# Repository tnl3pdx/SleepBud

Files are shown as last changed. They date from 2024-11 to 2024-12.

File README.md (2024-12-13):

## ECE 411 Team 3 - SleepBud
## Members
- Ameer Melli
- Cristian Gomez
- Paul Nguyen
- Truong Le

## Product Overview
Sleep Bud transcends the functionality of a simple alarm clock, serving as a comprehensive sleep companion designed to enhance your sleep quality. It features mood-inducing lights and gentle non-intrusive waking sounds. Essentially, this innovative device is a hybrid between a traditional alarm clock and a multi-color lamp.
Why?? Because according to the CDC 70 million Americans have chronic sleep problems and the current market solutions are too expensive. 

## User Manual for SleepBud

Mode 0: (normal mode indicated by teal colored colon)
- This will be where the clock will display the appropriate time.
- (mode button) Button 0 pressed in mode 0 will change the mode.
- (plus button) Button 1 pressed in mode 0 will increase the brightness of the lamp.
- (minus button) Button 2 pressed in mode 0 will decrease the brightness of the lamp.
- (select button) Button 3 pressed in mode 0 will cycle through lamp colors.

- In mode 0, when the alarm is set the bottom colon will be purple indicating the alarm is set.
- In mode 0, when the alarm is set, button 3 (the select button) acts as a snooze button.

- In mode 0, when in AM time (00:00 - 12:00) the digits will be a warm color (orange).
- In mode 0, when in PM time (12:00 - 24:00) the digits will be a cool color (white).

- In mode 0, when waving your hand over the alarm, the PIR sensor will automatically turn off the lamp if it is on and if it is off, it will turn it on.

Mode 1: (configuration time mode indicated by red colored colon)
- This will be where the user can manually set the clock time.
- (mode button) Button 0 pressed in mode 1 will cycle to the next mode and set the new time.
- (plus button) Button 1 pressed in mode 1 will increase the value of the selected section for the manual time.
- (minus button) Button 2 pressed in mode 1 will decrease the value of the selected section for the manual time.
- (select button) Button 3 pressed in mode 1 will cycle through the digits.

Mode 2: (enable alarm mode indicated by green colored colon)
- This will be for toggling the alarm on and off.
- (mode button) Button 0 pressed in mode 2 will cycle to the next mode and set the alarm.
- (plus button) Button 1 pressed in mode 2 will toggle on (1).
- (minus button) Button 2 pressed in mode 2 will toggle off (0).

Mode 3: (configuration alarm mode indicated by purple colored colon)
- This is for setting the alarm time.
- (mode button) Button 0 pressed in mode 3 will cycle to the next mode and set the new alarm time.
- (plus button) Button 1 pressed in mode 3 will increase the value of the selected section for the alarm time.
- (minus button) Button 2 pressed in mode 3 will decrease the value of the selected section for the alarm time.
- (select button) Button 3 pressed in mode 3 will cycle through the digits colors.

Mode 4: (select UTC mode indicated by yellow colored colon)
- This sets the UTC offset.
- (mode button) Button 0 pressed in mode 4 will cycle to the next mode and set the new UTC offset.
- (plus button) Button 1 pressed in mode 4 will increase the value of the selected section for the UTC offset.
- (minus button) Button 2 pressed in mode 4 will decrease the value of the selected section for the UTC offset.

- In mode 4, when indicating what UTC offset you want when adding a positive offset the digits will be green.
- In mode 4, when indicating what UTC offset you want when adding a negative offset the digits will be red.

Mode 5: (enable NTP update mode indicated by pink colored colon)
- This enables time fetch from wifi and applies UTC offset.
- (mode button) Button 0 pressed in mode 5 will cycle to the next mode and set enable NTP.
- (plus button) Button 1 pressed in mode 5 will toggle on (1).
- (minus button) Button 2 pressed in mode 5 will toggle off (0).

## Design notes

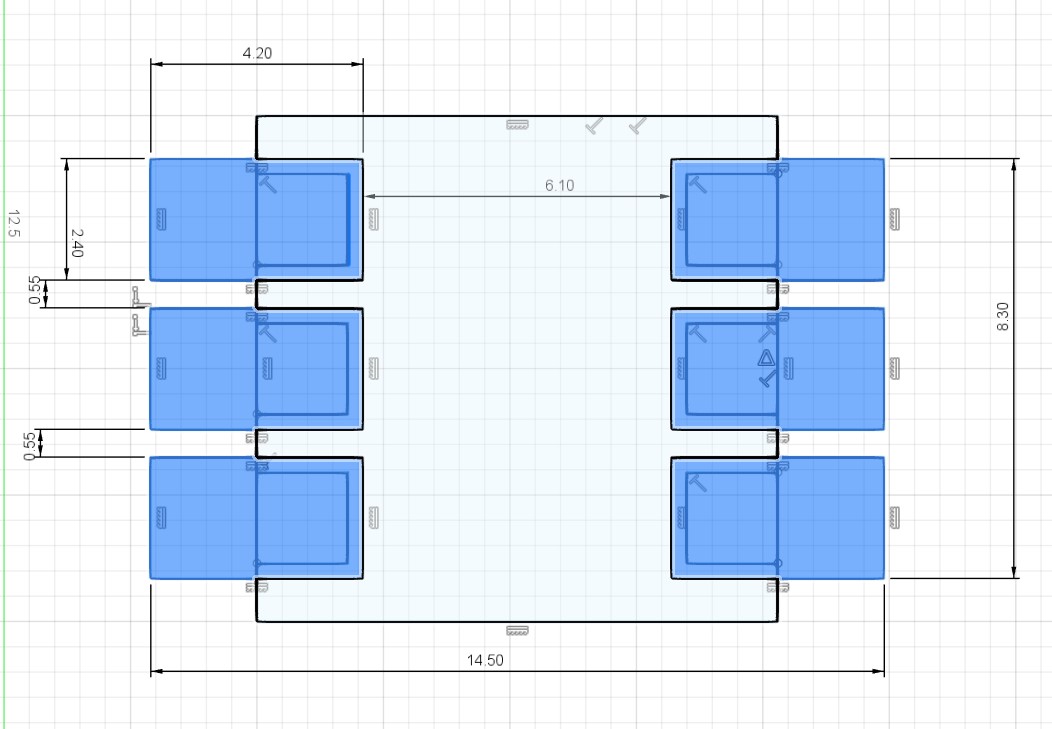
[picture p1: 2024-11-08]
Images/Sketches/WS2128B-CustomPadLayout.jpg

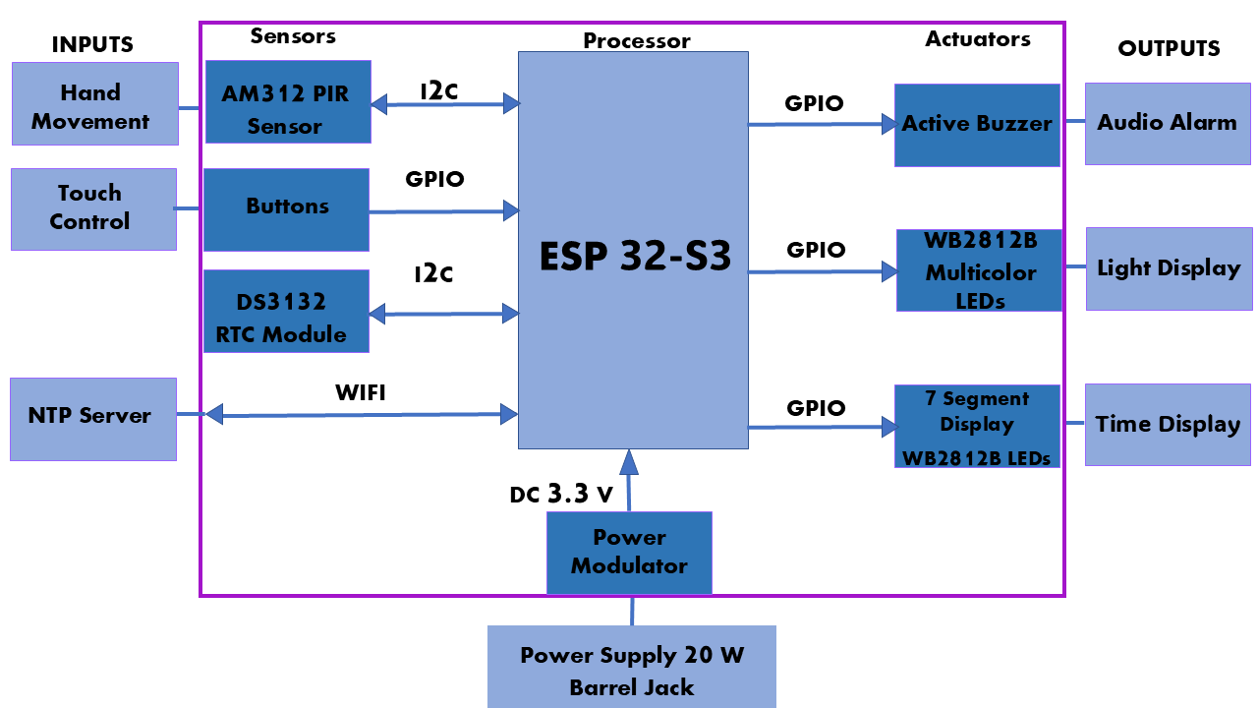
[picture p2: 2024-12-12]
Images/Sketches/L1 v3.png

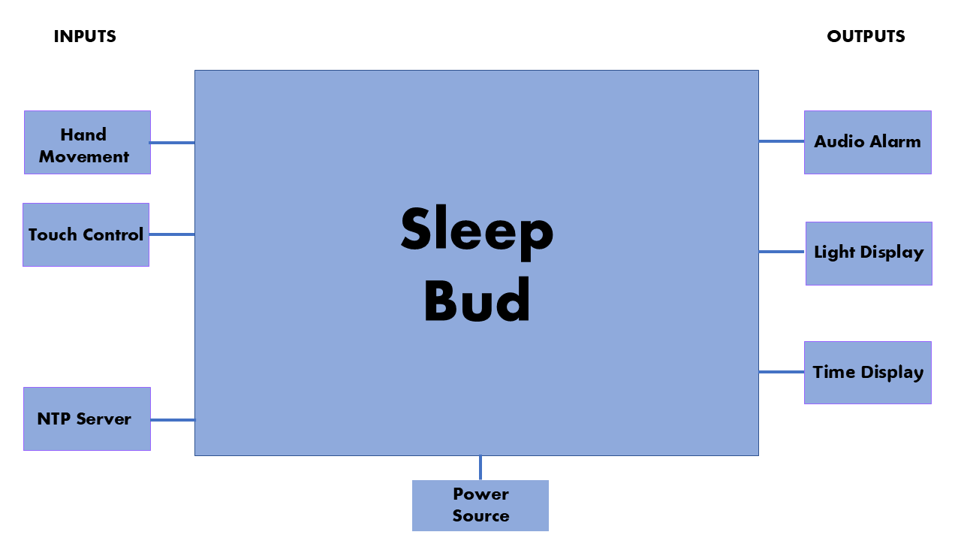
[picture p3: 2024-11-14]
Images/Sketches/L0 v2.png

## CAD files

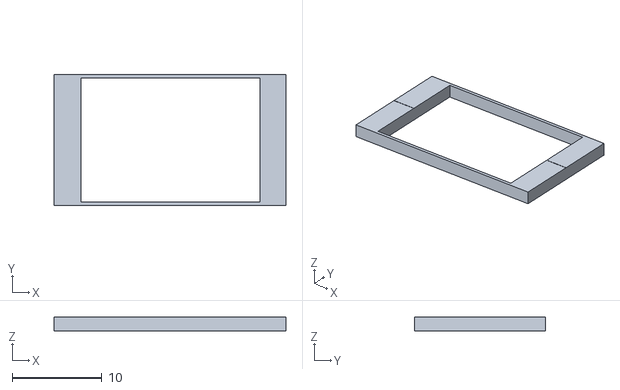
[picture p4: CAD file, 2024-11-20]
3D_Prints/Extra Parts/KillSwitch_V2_ECE411.stl
25.9 x 14.6 x 1.60

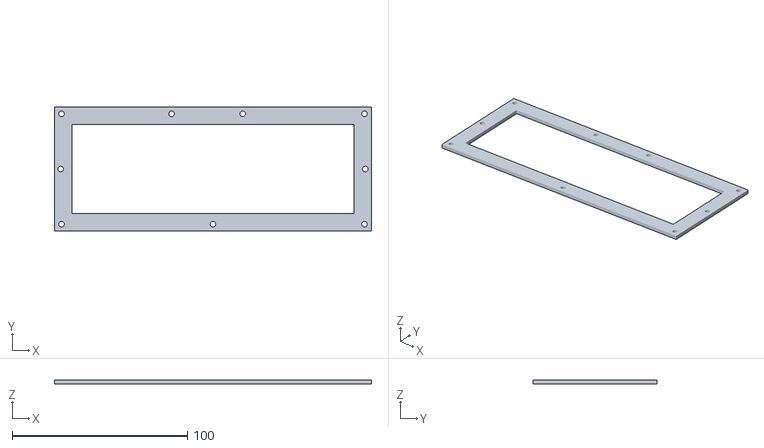
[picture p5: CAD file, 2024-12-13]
3D_Prints/SBFrontA.stl
181.0 x 71.0 x 2.50

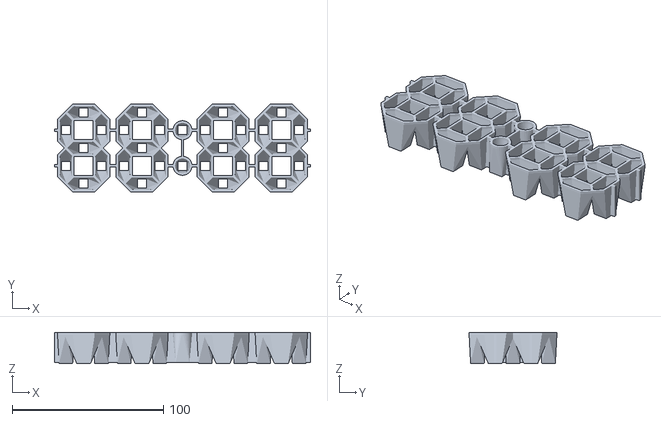
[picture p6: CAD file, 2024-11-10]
3D_Prints/Extra Parts/ClockDigits_V1_ECE411.stl
169.0 x 58.0 x 20.8

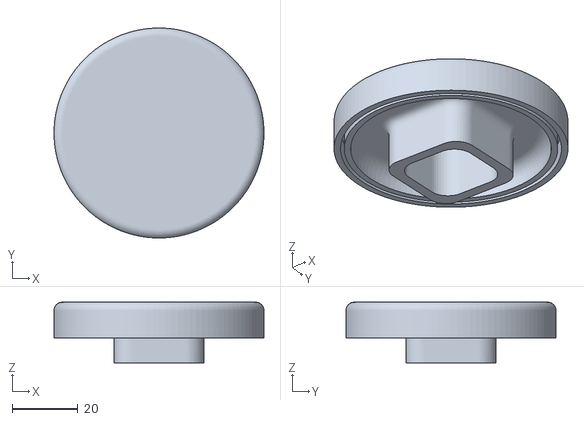
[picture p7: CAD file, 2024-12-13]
3D_Prints/SBCap.stl
64.0 x 64.0 x 18.5

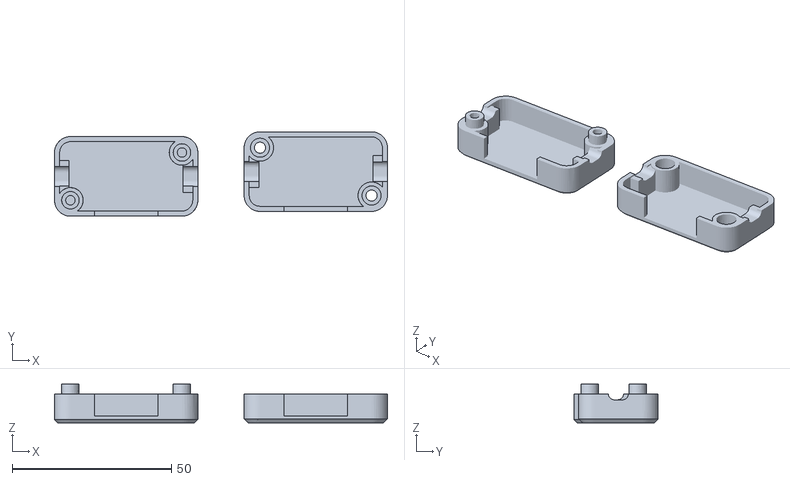
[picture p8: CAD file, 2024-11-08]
3D_Prints/Extra Parts/Kill_Switch_box_ECE411.stl
104.5 x 26.5 x 12.1

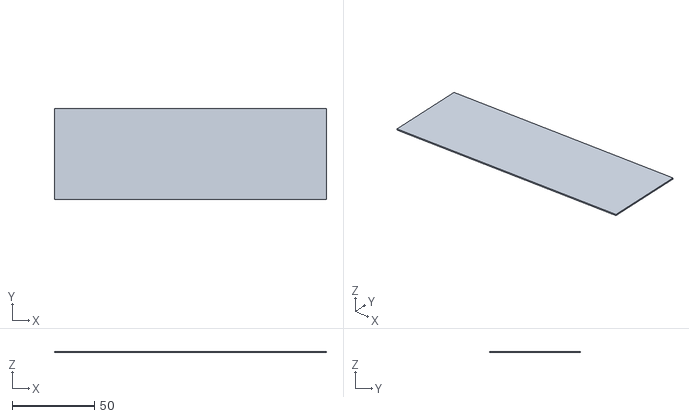
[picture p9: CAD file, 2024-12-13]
3D_Prints/SBFrontC.stl
165.0 x 55.0 x 0.8

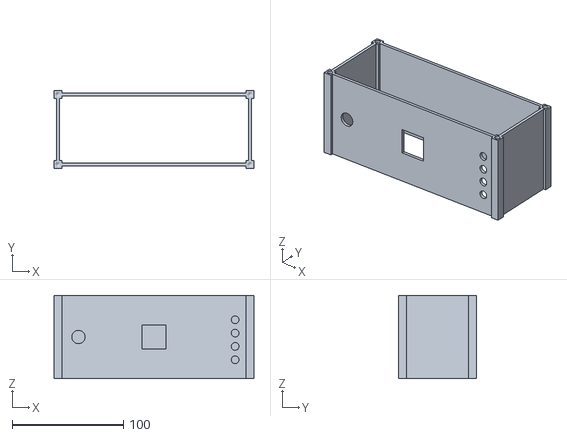
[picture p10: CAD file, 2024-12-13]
3D_Prints/SBBody.stl
180.0 x 70.0 x 75.0

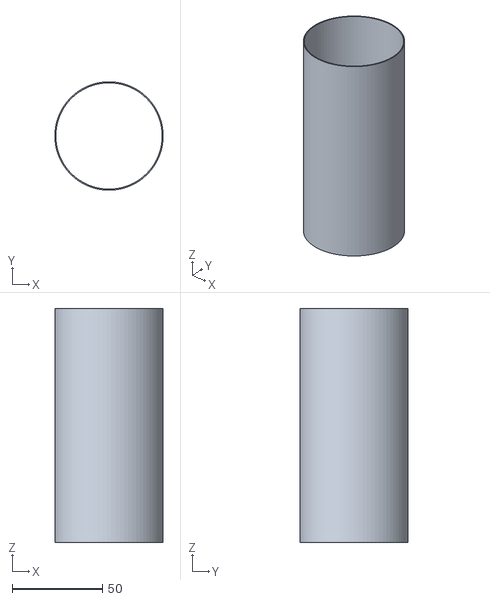
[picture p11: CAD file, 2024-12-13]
3D_Prints/SBShell.stl
60.0 x 60.0 x 129.5

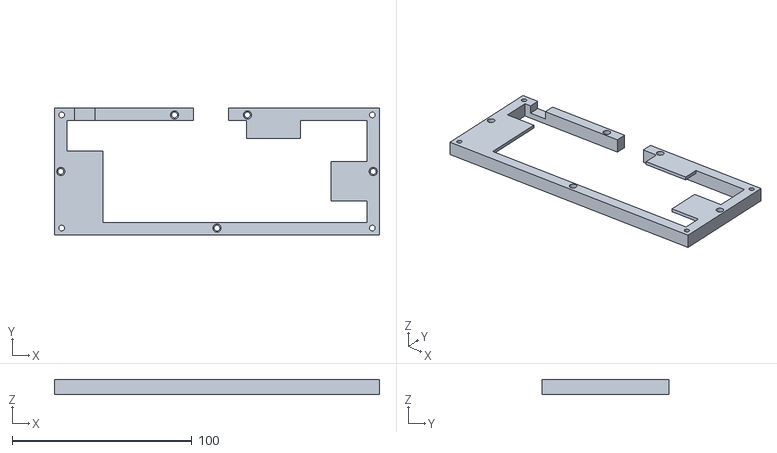
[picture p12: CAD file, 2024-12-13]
3D_Prints/SBFrontB.stl
181.0 x 71.0 x 8.50

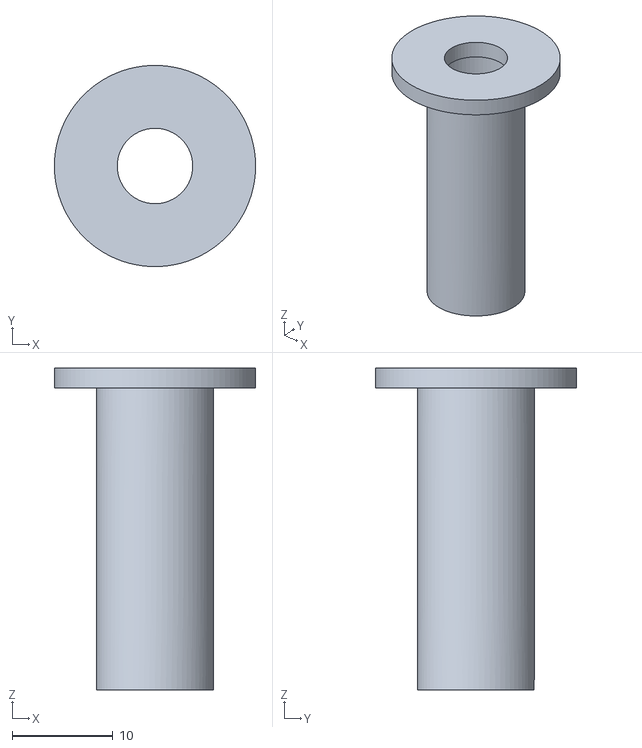
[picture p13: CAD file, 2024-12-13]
3D_Prints/SBPIR.stl
20.0 x 20.0 x 32.0

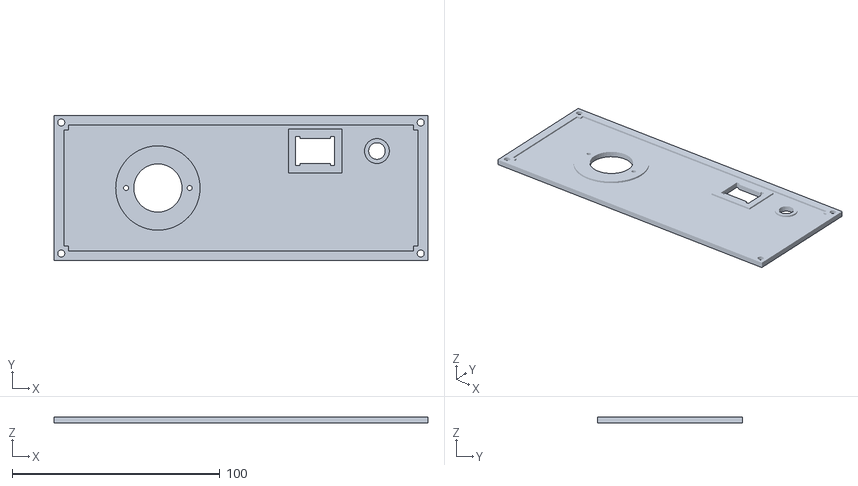
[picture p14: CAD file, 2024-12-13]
3D_Prints/SBBack.stl
180.0 x 70.0 x 3.00

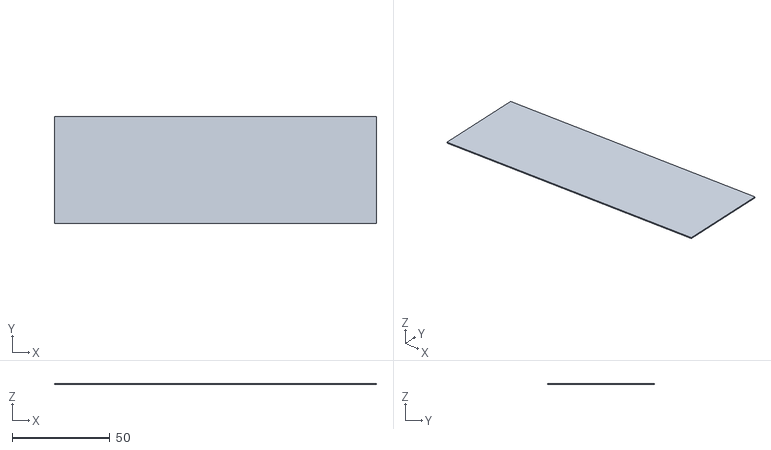
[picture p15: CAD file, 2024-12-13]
3D_Prints/SBFrontC-3Layer.stl
165.0 x 55.0 x 0.6

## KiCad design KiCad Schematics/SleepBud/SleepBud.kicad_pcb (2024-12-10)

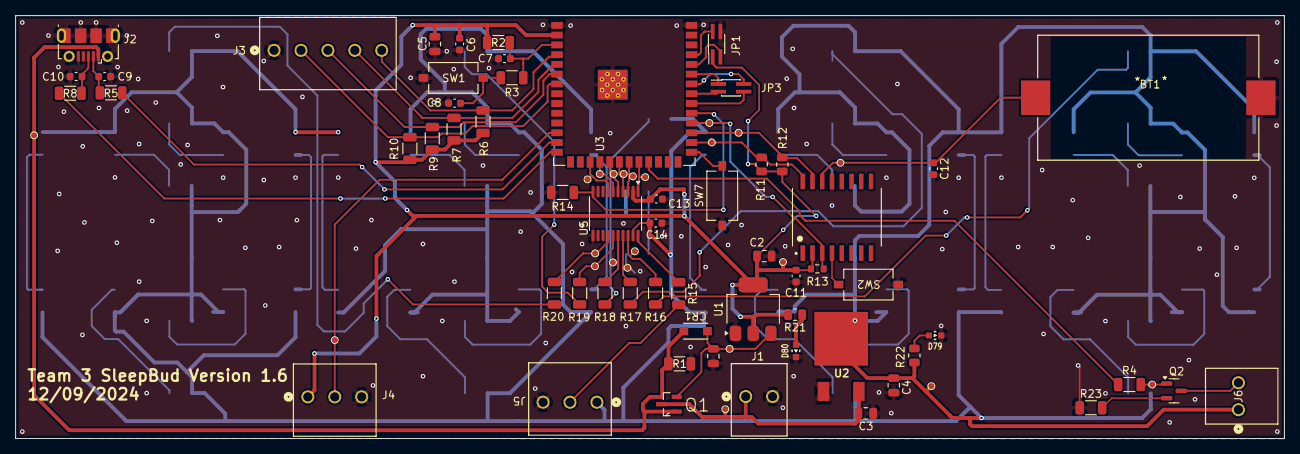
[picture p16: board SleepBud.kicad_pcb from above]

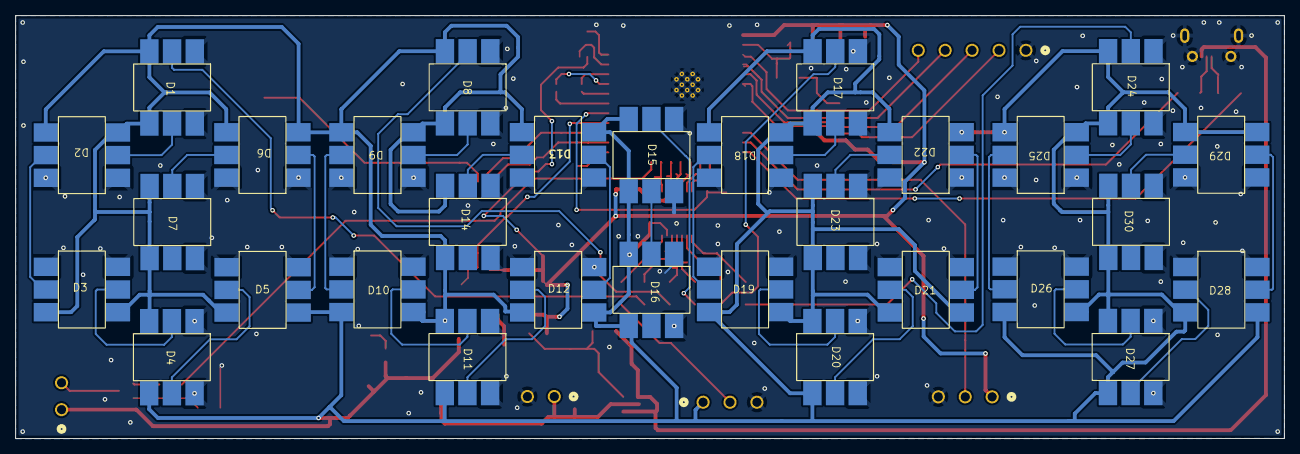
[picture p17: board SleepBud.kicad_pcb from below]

Board: 2 copper layers, 165.0 x 55.0 mm, 111 parts (30 on the bottom side), 79 nets.

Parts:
BT1: Battery_Cell_3V; BH-74G-5-P_ADM
C1, C3: 10uF; C_0805_2012Metric
C2, C4, C5: 22uF; C_0805_2012Metric
C6, C8, C11, C12, C13, C14: 0.1uF; C_0603_1608Metric
C7: 1uF; C_0603_1608Metric
C9, C10: 22pF; C_0603_1608Metric
CR1: MBR120LSFT3G; SDO_SOD-123FL498_OSI
D1, D2, D3, D4, D5, D6, D7, D8, D9, D10, D11, D12, D13, D14, D15, D16, D17, D18, D19, D20, D21, D22, D23, D24, D25, D26, D27, D28, D29, D30: WS2812B; WB2812B
D79, D80: WL-SMCW_0603
J1: 12V Barrel Jack; CONN_1984769_PXC
J2: USB_B_Micro; USB_Micro-B_Molex-105017-0001
J3: Button Connector; CONN_1984798_PXC
J4: AM312 Connector; CONN_1984772_PXC
J5: LED Lamp Connector; CONN_1984772_PXC
J6: Connector to Buzzer; CONN_1984769_PXC
JP1: UART; PinHeader_2x02_P1.00mm_Vertical_SMD
JP3: JTAG; PinHeader_2x02_P1.00mm_Vertical_SMD
Q1: DMG3415U-7; SOT95P240X105-3N
Q2: AO3400A; SOT-23
R1, R2, R6, R7, R9, R10, R23: 10k; R_1206_3216Metric
R3, R5, R8: 0; R_1206_3216Metric
R4, R15, R16, R17, R18, R19, R20: 470; R_1206_3216Metric
R11, R12: 3.3k; R_0805_2012Metric
R13: 4.7k; R_0603_1608Metric
R14: 10kOhm; R_1206_3216Metric
R21: 100; R_0805_2012Metric
R22: 180; R_0805_2012Metric
SW1: EN Button; SW_Tactile_SPST_NO_Straight_CK_PTS636Sx25SMTRLFS
SW2: Reset Button; SW_Tactile_SPST_NO_Straight_CK_PTS636Sx25SMTRLFS
SW7: Boot Button; SW_Tactile_SPST_NO_Straight_CK_PTS636Sx25SMTRLFS
TP1, TP2, TP3, TP4, TP5, TP6, TP7, TP8, TP9, TP10, TP11, TP12, TP13, TP14, TP15, TP22: TestPoint_Flag; Testpoint Pad
TP16, TP17, TP18, TP19, TP20, TP21: TestPoint_Small; Testpoint Pad
U1: AMS1117-3.3; SOT-223-3_TabPin2
U2: AZ1084CD
U3: ESP32-S3-WROOM-1
U4: DS3231SN_; SOIC127P1032X265-16N
U5: TXS0108EPW; TSSOP-20_4.4x6.5mm_P0.65mm

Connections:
+3.3V: C2.1, C5.1, C6.1, C11.1, C13.1, J4.1, JP1.1 (VCC), R2.1, R6.1, R7.1, R9.1, R10.1, R11.1, R12.1, R13.1, R21.2, TP8.1, U1.2 (VO), U3.2 (3V3), U4.2 (VCC), U5.2 (VCCA)
+5V: C4.1, C14.1, D1.1 (VDD), D2.1 (VDD), D3.1 (VDD), D4.1 (VDD), D5.1 (VDD), D6.1 (VDD), D7.1 (VDD), D8.1 (VDD), D9.1 (VDD), D10.1 (VDD), D11.1 (VDD), D12.1 (VDD), D13.1 (VDD), D14.1 (VDD), D15.1 (VDD), D16.1 (VDD), D17.1 (VDD), D18.1 (VDD), D19.1 (VDD), D20.1 (VDD), D21.1 (VDD), D22.1 (VDD), D23.1 (VDD), D24.1 (VDD), D25.1 (VDD), D26.1 (VDD), D27.1 (VDD), D28.1 (VDD), D29.1 (VDD), D30.1 (VDD), J5.1, J6.1, R22.2, TP7.1, U2.2 (VO), U5.19 (VCCB)
+12V: C3.1, J1.1, Q1.3 (D), TP6.1, U2.3 (VI)
/B2 - Digit 1: R16.1, TP5.1, U5.18 (B2)
/B3 - Digit 2: R17.1, TP4.1, U5.17 (B3)
/B4 - Colon: R18.1, TP3.1, U5.16 (B4)
/B5 - Digit 3: R19.1, TP2.1, U5.15 (B5)
/B6 - Digit 4: R20.1, TP1.1, U5.14 (B6)
/Buzzer: R4.1, U3.23 (IO21)
/IO8 - Output2: J4.2, TP11.1, U3.12 (IO8)
/IO9 - A6: TP21.1, U3.17 (IO9), U5.7 (A6)
/IO10 - A5: TP20.1, U3.18 (IO10), U5.6 (A5)
/IO11 - A4: TP19.1, U3.19 (IO11), U5.5 (A4)
/IO12 - A3: TP18.1, U3.20 (IO12), U5.4 (A3)
/IO13 - A2: TP17.1, U3.21 (IO13), U5.3 (A2)
/IO14 - A1: TP16.1, U3.22 (IO14), U5.1 (A1)
/IO35-SCL: R11.2, TP13.1, U3.28 (IO35), U4.16 (SCL)
/IO36-SDA: R12.2, TP14.1, U3.29 (IO36), U4.15 (SDA)
/IO37-SQW/INT: R13.2, TP15.1, U3.30 (IO37), U4.3 (SQW/~INT)
/IO38-OE: R14.1, U3.31 (IO38), U5.10 (OE)
GND: BT1.2 (-), C1.2, C2.2, C3.2, C4.2, C5.2, C6.2, C7.1, C8.1, C9.2, C10.2, C11.2, C12.2, C13.2, C14.2, D1.3 (VSS), D2.3 (VSS), D3.3 (VSS), D4.3 (VSS), D5.3 (VSS), D6.3 (VSS), D7.3 (VSS), D8.3 (VSS), D9.3 (VSS), D10.3 (VSS), D11.3 (VSS), D12.3 (VSS), D13.3 (VSS), D14.3 (VSS), D15.3 (VSS), D16.3 (VSS), D17.3 (VSS), D18.3 (VSS), D19.3 (VSS), D20.3 (VSS), D21.3 (VSS), D22.3 (VSS), D23.3 (VSS), D24.3 (VSS), D25.3 (VSS), D26.3 (VSS), D27.3 (VSS), D28.3 (VSS), D29.3 (VSS), D30.3 (VSS), D79.1, D80.1, J1.2, J2.5 (GND), J2.6 (Shield), J3.1, J4.3, J5.3, JP1.4 (GND), R1.2, R14.2, R23.1, SW1.1, SW2.1, SW7.1, U1.1 (GND), U2.1 (GND), U3.1 (GND), U3.40 (GND), U3.41 (GND), U4.13 (GND), U5.11 (GND)
unnamed: BT1.1 (+), C12.1, TP22.1, U4.14 (VBAT)
unnamed: C8.2, R3.1, SW1.2
unnamed: D1.4 (DIN), R16.2
unnamed: D1.2 (DOUT), D2.4 (DIN)
unnamed: D2.2 (DOUT), D3.4 (DIN)
unnamed: D3.2 (DOUT), D4.4 (DIN)
unnamed: D4.2 (DOUT), D5.4 (DIN)
unnamed: D5.2 (DOUT), D6.4 (DIN)
unnamed: D6.2 (DOUT), D7.4 (DIN)
unnamed: D8.4 (DIN), R17.2
unnamed: D8.2 (DOUT), D9.4 (DIN)
unnamed: D9.2 (DOUT), D10.4 (DIN)
unnamed: D10.2 (DOUT), D11.4 (DIN)
unnamed: D11.2 (DOUT), D12.4 (DIN)
unnamed: D12.2 (DOUT), D13.4 (DIN)
unnamed: D13.2 (DOUT), D14.4 (DIN)
unnamed: D15.4 (DIN), R18.2
unnamed: D15.2 (DOUT), D16.4 (DIN)
unnamed: D17.4 (DIN), R19.2
unnamed: D17.2 (DOUT), D18.4 (DIN)
unnamed: D18.2 (DOUT), D19.4 (DIN)
unnamed: D19.2 (DOUT), D20.4 (DIN)
unnamed: D20.2 (DOUT), D21.4 (DIN)
unnamed: D21.2 (DOUT), D22.4 (DIN)
unnamed: D22.2 (DOUT), D23.4 (DIN)
unnamed: D24.4 (DIN), R20.2
unnamed: D24.2 (DOUT), D25.4 (DIN)
unnamed: D25.2 (DOUT), D26.4 (DIN)
unnamed: D26.2 (DOUT), D27.4 (DIN)
unnamed: D27.2 (DOUT), D28.4 (DIN)
unnamed: D28.2 (DOUT), D29.4 (DIN)
unnamed: D29.2 (DOUT), D30.4 (DIN)
unnamed: D79.2, R22.1
unnamed: D80.2, R21.1
unnamed: C10.1, J2.3 (D+), R8.2
unnamed: C9.1, J2.2 (D-), R5.2
unnamed: J5.2, R15.2
unnamed: JP1.3 (RXD0), U3.36 (RXD0)
unnamed: JP1.2 (TXD0), U3.37 (TXD0)
unnamed: JP3.4 (TCK), U3.32 (IO39)
unnamed: JP3.2 (TDI), U3.34 (IO41)
unnamed: JP3.3 (TDO), U3.33 (IO40)
unnamed: JP3.1 (TMS), U3.35 (IO42)
unnamed: C1.1, CR1.1, Q1.2 (S), TP9.1, U1.3 (VI)
unnamed: J6.2, Q2.3 (D)
unnamed: Q2.1 (G), R4.2, TP12.1
unnamed: Q2.2 (S), R23.2
unnamed: C7.2, R2.2, R3.2, U3.3 (EN)
unnamed: SW7.2, U3.27 (IO0)
unnamed: J3.5, R6.2, U3.4 (IO4)
unnamed: J3.4, R7.2, U3.5 (IO5)
unnamed: J3.3, R9.2, U3.6 (IO6)
unnamed: J3.2, R10.2, U3.7 (IO7)
unnamed: R5.1, U3.13 (IO19)
unnamed: R8.1, U3.14 (IO20)
unnamed: SW2.2, U4.4 (~RST)
unnamed: R15.1, U5.20 (B1)
VBUS: CR1.2, J2.1 (VBUS), Q1.1 (G), R1.1, TP10.1

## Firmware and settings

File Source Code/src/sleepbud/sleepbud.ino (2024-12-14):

/* Notes:

Include the LEDs to change depending on mode (and if alarm on or off)
Ensure brightness can be adjusted for the lamp ( I use fast led lib)
Does switching modes work properly and does it interupt the time in main loop
Does the UTC actually work as expected?
Does the alarm work at the set time
Does the snooze work (  RTC.enableAlarmPin(); ) where it says and ensure it works
Check that the time is actually changed after setting it manually

Comprehensive test:
does mode 0 adjust brightness and snooze correctly

Does mode 1 adjust the time correctly (go back to mode 0 and check)

Does mode 2 turn on the alarm correctly for the set alarm time (check mode 0 if mode lights are on and if buzzer goes off at that time)

Does mode 3 adjust the UTC offset correctly (check mode 0 for corrected time)

Does mode 4 manually set the time correctly (check mode 0 for time changed)
*/

//***** Libraries *****//

//* RTC Clock Library & Dependencies
#include <I2C_RTC.h>
#include <Wire.h>

//* ESP32 Wifi and NTP Libraries
#include <WiFi.h>
#include <NTPClient.h>
#include <WiFiUdp.h>

//* LED Control
#include <FastLED.h>

//* NVS Intefacing Libaries
#include <Preferences.h>

//* Misc. Libraries
#include "creds.h"
#include "config.h"

//***** Defines *****//
//#define DEBUG
#define TOTALBUTTONS 4
#define NUMMODES  6
#define TOTALCOLORS 6

//***** Function Prototypes *****//

// Menu UI Functions
void pollButtons();
void pollPIR();
void updateModeIndicator();
void ui_normalLoop();
void ui_configTime();
void ui_enableAlarm();
void ui_configAlarm();
void ui_selectUTC();
void ui_enableNTPUpdate();

// General Setup Functions
void genSetup();
void wifiNTP();

// Helper Functions
void setDigitLED(int num, uint8_t hue, uint8_t sat, uint8_t val, uint8_t select);
void timeDisplay(uint8_t hue, uint8_t sat, uint8_t mode);
void setAuxLED(bool type, uint8_t hue, uint8_t sat, uint8_t val);
long UTCToSeconds(short utcOffsetTriplet[]);

// ISR Functions
void alarmISR();
void isrPIR();

// Debug Functions
void testLEDs();
void testDigits();


//***** Objects *****//

//* LED Objects
CRGB digiLEDS[4][NDIGILEDS];
CRGB modeLEDS[NMODELEDS];
CRGB lampLEDS[NLAMPLEDS];

//* RTC and WiFi Objects
static DS3231 RTC;
WiFiUDP ntpPort;
NTPClient timeClient(ntpPort, "time.nist.gov");

//* NVS Objects
Preferences nvsObj;

//***** Global Variables *****//

/* UTC Offset Data: 
	{HOUR, MINUTE, TYPE}

	NEGATIVE	-	RED 	(0)
	NEUTRAL		- WHITE (1)
	POSITIVE	- GREEN (2)
*/
short utcOffsetArray[38][3] = {
	{12, 0, 0},   {11, 0, 0},   {10, 0, 0},   {9, 30, 0}, 
	{9, 0, 0},    {8, 0, 0},    {7, 0, 0},    {6, 0, 0}, 
	{5, 0, 0},    {4, 0, 0},    {3, 30, 0},   {3, 0, 0}, 
	{2, 0, 0},    {1, 0, 0},    {0, 0, 1},    {1, 0, 2}, 
	{2, 0, 2},    {3, 0, 2},    {3, 30, 2},   {4, 0, 2}, 
	{4, 30, 2},   {5, 0, 2},    {5, 30, 2},   {5, 45, 2}, 
	{6, 0, 2},    {6, 30, 2},   {7, 0, 2},    {8, 0, 2}, 
	{8, 45, 2},   {9, 0, 2},    {9, 30, 2},   {10, 0, 2}, 
	{10, 30, 2},  {11, 0, 2},   {12, 0, 2},   {12, 45, 2}, 
	{13, 0, 2},   {14, 0, 2}
};

//* 7 Segment LED Reference Data
uint8_t ledRef[10][7] = {
	{1, 1, 1, 1, 1, 1, 0},    // 0
	{0, 1, 1, 0, 0, 0, 0},    // 1
	{1, 0, 1, 1, 0, 1, 1},    // 2
	{1, 1, 1, 1, 0, 0, 1},    // 3
	{0, 1, 1, 0, 1, 0, 1},    // 4
	{1, 1, 0, 1, 1, 0, 1},    // 5
	{1, 1, 0, 1, 1, 1, 1},    // 6
  {0, 1, 1, 1, 0, 0, 0},    // 7
  {1, 1, 1, 1, 1, 1, 1},    // 8
  {1, 1, 1, 1, 1, 0, 1}    // 9
};

//* Color table that holds hue/sat for mode select
int colorTable[TOTALCOLORS][2] = {
    {0, 0},       // White
    {0, 255},     // Red
    {85, 255},    // Green
    {170, 255},   // Blue
    {42, 255},    // Yellow
    {212, 255}    // Purple
};

//* Button States
volatile bool minusPressed  = 0;
volatile bool plusPressed   = 0;
volatile bool selectPressed = 0;
volatile bool pressed[TOTALBUTTONS] = {0};

//* Menu UI Variables
int     modeCounter     = 0;  // Modes: 0 - 3
bool    alarmSet        = 0;  // Alarm state (off/on)
bool    alarmActive     = 0;  // Alarm currently ringing
uint8_t currentField    = 0;  // Field select or for modes 1 and 3

//* Timer for Debounce
unsigned long       lastPressTime     = 0;    // Last button press time
const unsigned int  debounceInterval  = 40;   // Debounce interval

//* Timer for PIR
unsigned long       lastPIRTrigger  = 0;
const unsigned int  pirDelay        = 3000;

//* Timer for blink
unsigned long       lastBlink       = 0;
const unsigned int  blinkDelay      = 500;
bool blinkToggle = 0;

//* Data Values for Clock
uint8_t hms[3];
uint8_t rtcAlarm[2];

//* Configuration Variables
bool      timeUpdate;
uint8_t   lampBrightVal;
uint8_t   utcOffset;

//* WiFi Credentials
const char *ssid = WIFI_SSID;
const char *pswrd = WIFI_PASSWORD;

//* Setting Variables
volatile bool lampEN = 1;
bool uiDoOnce = 0;
bool resetNVS = 0;
bool madeEdit = 0;
int selected_digit = 0;
uint8_t dispBrightVal = 50;   // Default display brightness
uint8_t maxLampBright = 204;  // 80% of max brightness
uint8_t colorPick = 0;


//***** Main Program *****//
void setup() {
  Serial.begin(115200);

  genSetup();

  if (timeUpdate == 1) {
    wifiNTP();
  }

  setAuxLED(0, 100, 127, dispBrightVal);
  if (lampEN == 1) {
    setAuxLED(1, 0, 0, lampBrightVal);
  }

  attachInterrupt(digitalPinToInterrupt(PIRPIN), isrPIR, RISING);
  #ifdef DEBUG
  Serial.println("Setup complete");
  #endif
  
}

void loop() {
	
  // Reattach PIR Interrupt
  if ((millis() - lastPIRTrigger > pirDelay) && (!digitalRead(PIRPIN))) {
    attachInterrupt(digitalPinToInterrupt(PIRPIN), isrPIR, RISING);
  }

  if (lampEN == 1) {
    setAuxLED(1, colorTable[colorPick][0], colorTable[colorPick][1], lampBrightVal);
  } else {
    setAuxLED(1, 0, 0, 0);
  }

	pollButtons();

  // Handle modes
  switch (modeCounter) {
    case 0:
      ui_normalLoop();
      break;
    case 1:
      ui_configTime();
      break;
    case 2:
      ui_enableAlarm();
      break;
    case 3:
      ui_configAlarm();
      break;
    case 4:
      ui_selectUTC();
      break;
    case 5:
      ui_enableNTPUpdate();
      break;  
  }

  FastLED.show();

}

void pollButtons() {

  // Reset pressed state for mode button
  if (digitalRead(MODEBUTTON) == 1) {
    pressed[0] = 0;
  }

    // Reset pressed state for UP button
  if (digitalRead(UPBUTTON) == 1) {
    pressed[1] = 0;
  }

    // Reset pressed state for DOWN button
  if (digitalRead(DOWNBUTTON) == 1) {
    pressed[2] = 0;
  }
  
  // Reset pressed state for select button
  if (digitalRead(SWITCHBUTTON) == 1) {
    pressed[3] = 0;
  }
  
	// Check if there has been a button pressed recently
  if (millis() - lastPressTime > debounceInterval) {
		if (digitalRead(MODEBUTTON) == 0) {
      // Check if mode button has been released (one press -> one action only)
      if (!pressed[0]) {

        // we just left mode 1 and this sets the time
        if (modeCounter == 1) {
          // This is for after all digits are selected correctly
          if (RTC.isRunning() && (madeEdit == 1)) {  // Stop clock for configuration 
            RTC.stopClock();
            RTC.setTime(hms[0], hms[1], hms[2]);
            RTC.startClock();
          }
        } else if (modeCounter == 2) {
          if (madeEdit == 1) {
            if (alarmSet == 1) {
              RTC.enableAlarm1();
            } else {
              RTC.disableAlarm1();
            }
          }
        } else if (modeCounter == 3) {
            if (RTC.isRunning() && (madeEdit == 1)) {
              RTC.setAlarm1(rtcAlarm[0], rtcAlarm[1], 0);
              nvsObj.begin("config", false);
              nvsObj.putInt("alarmHr", rtcAlarm[0]);
              nvsObj.putInt("alarmMin", rtcAlarm[1]);
              nvsObj.end();
            }
        } else if (modeCounter == 4) {
            if (madeEdit == 1) {
              nvsObj.begin("config", false);
              nvsObj.putInt("utcOffset", utcOffset);
              nvsObj.end();
              #ifdef DEBUG
              Serial.printf("UTC changed to: %d\n", utcOffset);
              #endif
            }
        } else if (modeCounter == 5) {
          if (madeEdit == 1) {
            nvsObj.begin("config", false);
            nvsObj.putBool("timeUpdate", timeUpdate);
            nvsObj.end();
          }
        }

        modeCounter = (modeCounter + 1) % NUMMODES;

        #ifdef DEBUG
        Serial.printf("Mode changed to: %d\n", modeCounter);
        #endif

        updateModeIndicator();

        madeEdit = 0;
        selected_digit = 0;
        uiDoOnce = 0;
        pressed[0] = 1;
      }
    } else if (digitalRead(UPBUTTON) == 0) {
      if (!pressed[1]) {
        plusPressed = 1;
        #ifdef DEBUG
        Serial.printf("Plus Pressed\n");
        #endif
        pressed[1] = 1;
      }
    } else if (digitalRead(DOWNBUTTON) == 0) {
      if (!pressed[2]) {
        minusPressed = 1;
        #ifdef DEBUG
        Serial.printf("Minus Pressed\n");
        #endif
        pressed[2] = 1;
      }
    } else if (digitalRead(SWITCHBUTTON) == 0) {
      if (!pressed[3]) {
        selectPressed = 1;
        #ifdef DEBUG
        Serial.printf("Select Pressed\n");
        #endif
        pressed[3] = 1;
      }
    }
		lastPressTime = millis();
	}

}

void pollPIR() {
  if (millis() - lastPIRTrigger > pirDelay) {
    if (digitalRead(PIRPIN) == 1) {
      if (lampEN) {
        lampEN = 0;
      } else {
        lampEN = 1;
      }
    }

    lastPIRTrigger = millis();
  }
}

// Update Mode Indicator
void updateModeIndicator() {
  uint8_t hue, sat;

  switch (modeCounter) {
    case 0: hue = 100; sat = 127;     break;    // Teal
    case 1: hue = 0; sat = 255;       break;    // Red
    case 2: hue = 85; sat = 255;      break;    // Green
    case 3: hue = 170; sat = 255;     break;    // Purple
    case 4: hue = 42; sat = 255;      break;    // Yellow
    case 5: hue = 212; sat = 255;     break;    // Pink
  }

  setAuxLED(0, hue, sat, dispBrightVal);
}

// Mode Handlers
void ui_normalLoop() {

  // Display Time
  if(RTC.isRunning()) {
    #ifdef DEBUG
    Serial.printf("Current Time: %d:%d:%d\n", RTC.getHours(), RTC.getMinutes(), RTC.getSeconds());
    #endif

    if (RTC.getHours() > 12) {
      timeDisplay(0, 0, 0);
    } else {
      timeDisplay(35, 167, 0);
    }
  }

  if (plusPressed) {
    lampBrightVal = constrain(lampBrightVal + 10, 0, maxLampBright);

    #ifdef DEBUG
    Serial.printf("Brightness increased to: %d\n", lampBrightVal);
    #endif

    nvsObj.begin("config", false);
    nvsObj.putInt("lampBrightVal", lampBrightVal);
    nvsObj.end();

    plusPressed = 0;
  } else if (minusPressed) {
    lampBrightVal = constrain(lampBrightVal - 10, 0, maxLampBright);

    #ifdef DEBUG
    Serial.printf("Brightness decreased to: %d\n", lampBrightVal);
    #endif

    nvsObj.begin("config", false);
    nvsObj.putInt("lampBrightVal", lampBrightVal);
    nvsObj.end();

    minusPressed = 0;
  } else if (selectPressed) {
    if (alarmActive) {
      RTC.clearAlarm1();
      RTC.disableAlarm1();
      digitalWrite(BUZZPIN, LOW);
      setAuxLED(0, 100, 127, dispBrightVal);
      FastLED.show();
      alarmActive = 0;
      alarmSet = 0;

    } else {
      colorPick = (colorPick + 1) % TOTALCOLORS;
      
      #ifdef DEBUG
      Serial.printf("Color selected is: %d\n", colorPick);
      #endif
    }
    selectPressed = 0; 
  }
}

void ui_configTime() {
  // Obtain RTC Data to put as initial values
  if (uiDoOnce == 0) {
    hms[0] = RTC.getHours();
    hms[1] = RTC.getMinutes();
    hms[2] = 0;
    uiDoOnce = 1;
  }

  // 0 - 24 (hours) and 0 - 59 (minutes) feild
  if (selectPressed) {
    if (selected_digit){
      selected_digit = 0;
    }else if (selected_digit == 0)
    {
      selected_digit = 1;
    }
    madeEdit = 1;
    selectPressed = 0;
  }

  //Chnaging first and second digits (hours)
  if (selected_digit == 0) {
    if (plusPressed) {
      hms[selected_digit] = constrain(hms[selected_digit] + 1, 0, 24); // only setting 1 or zero for hour
      madeEdit = 1;
      plusPressed = 0;
    }
    if (minusPressed) {
      hms[selected_digit] = constrain(hms[selected_digit] - 1, 0, 24); // only setting 1 or zero for hour
      madeEdit = 1;
      minusPressed = 0;
    }
    timeDisplay(0, 0, 1);
  }

  //Chnaging second and third digits (minutes)
  if (selected_digit == 1) {
    if (plusPressed){
      hms[selected_digit] = constrain(hms[selected_digit] + 1, 0, 59); // only setting 1 or zero for hour
      madeEdit = 1;
      plusPressed = 0;
    }
    if (minusPressed){
      hms[selected_digit] = constrain(hms[selected_digit] - 1, 0, 59); // only setting 1 or zero for hour
      madeEdit = 1;
      minusPressed = 0;
    }
    timeDisplay(0, 0, 1);
  }

}

void ui_enableAlarm() {
  
  hms[0] = 0;
  hms[1] = (uint8_t)alarmSet;

  timeDisplay(0, 0, 1);

  if (plusPressed) {
    alarmSet = 1;

    #ifdef DEBUG
    Serial.printf("alarmSet is: %d\n", alarmSet);
    #endif

    madeEdit = 1;
    hms[1] = alarmSet;
    plusPressed = 0;
  } else if (minusPressed) {
    alarmSet = 0;

    #ifdef DEBUG
    Serial.printf("alarmSet is: %d\n", alarmSet);
    #endif

    madeEdit = 1;
    hms[1] = alarmSet;
    minusPressed = 0;
  } else if (selectPressed) {
    selectPressed = 0; 
  }
}

void ui_configAlarm() {

  // 0 - 24 (hours) and 0 - 59 (minutes) field
  if (selectPressed) {
    if (selected_digit){
      selected_digit = 0;
    } else if (selected_digit == 0)
    {
      selected_digit = 1;
    }
    madeEdit = 1;
    selectPressed = 0;
  }

  //Chnaging first and second digits (hours)
  if (selected_digit == 0) {
    if (plusPressed) {
      rtcAlarm[selected_digit] = constrain(rtcAlarm[selected_digit] + 1, 0, 24); // only setting 1 or zero for hour
      madeEdit = 1;
      plusPressed = 0;
    }
    if (minusPressed) {
      rtcAlarm[selected_digit] = constrain(rtcAlarm[selected_digit] - 1, 0, 24); // only setting 1 or zero for hour
      madeEdit = 1;
      minusPressed = 0;
    }
    timeDisplay(0, 0, 2);
  }

  //Chnaging second and third digits (minutes)
  if (selected_digit == 1) {
    if (plusPressed){
      rtcAlarm[selected_digit] = constrain(rtcAlarm[selected_digit] + 1, 0, 59); // only setting 1 or zero for hour
      madeEdit = 1;
      plusPressed = 0;
    }
    if (minusPressed){
      rtcAlarm[selected_digit] = constrain(rtcAlarm[selected_digit] - 1, 0, 59); // only setting 1 or zero for hour
      madeEdit = 1;
      minusPressed = 0;
    }
    timeDisplay(0, 0, 2);
  }
}

void ui_selectUTC() {

  hms[0] = utcOffsetArray[utcOffset][0];
  hms[1] = utcOffsetArray[utcOffset][1];


  if (UTCToSeconds(utcOffsetArray[utcOffset]) < 0) {
    timeDisplay(0, 255, 1);
  } else if (UTCToSeconds(utcOffsetArray[utcOffset]) > 0) {
    timeDisplay(85, 255, 1);
  } else {
    timeDisplay(0, 0, 1);
  }
  

  if (plusPressed) {
    utcOffset = constrain(utcOffset + 1, 0, 37);

    #ifdef DEBUG
    Serial.printf("UTC Array Selection: %d\n", utcOffset);
    #endif

    madeEdit = 1;
    plusPressed = 0;
  } else if (minusPressed) {
    utcOffset = constrain(utcOffset - 1, 0, 37);

    #ifdef DEBUG
    Serial.printf("UTC Array Selection: %d\n", utcOffset);
    #endif

    madeEdit = 1;
    minusPressed = 0;
  } else if (selectPressed) {
    selectPressed = 0; 
  }

}

void ui_enableNTPUpdate() {

  hms[0] = 0;
  hms[1] = (uint8_t)timeUpdate;

  timeDisplay(0, 0, 1);

  if (plusPressed) {
    timeUpdate = 1;

    #ifdef DEBUG
    Serial.printf("timeUpdate is: %d\n", timeUpdate);
    #endif

    madeEdit = 1;
    hms[1] = timeUpdate;
    plusPressed = 0;
  } else if (minusPressed) {
    timeUpdate = 0;

    #ifdef DEBUG
    Serial.printf("timeUpdate is: %d\n", timeUpdate);
    #endif

    madeEdit = 1;
    hms[1] = timeUpdate;
    minusPressed = 0;
  } else if (selectPressed) {
    selectPressed = 0; 
  }
}

void genSetup() {
  #ifdef DEBUG
  Serial.printf("Starting general setup.\n");
  #endif
  
  // Set pins for I2C
  Wire.setPins(SDAPIN, SCLPIN);

  // Setup OE for logic level shifter
  pinMode(TXSPIN, OUTPUT);
  digitalWrite(TXSPIN, HIGH);

  // Setup PIR pin
  pinMode(PIRPIN, INPUT_PULLDOWN);

  // Setup Buzzer Pin
  pinMode(BUZZPIN, OUTPUT);
  digitalWrite(BUZZPIN, LOW);

  // Setup RTC Interrupt Pin
  pinMode(DSINT, INPUT);
  attachInterrupt(digitalPinToInterrupt(DSINT), alarmISR, FALLING);

  // Initialize Buttons
  pinMode(MODEBUTTON, INPUT_PULLUP);
  pinMode(DOWNBUTTON, INPUT_PULLUP);
  pinMode(UPBUTTON, INPUT_PULLUP);
  pinMode(SWITCHBUTTON, INPUT_PULLUP);

  //** Fetch parameters from non-volatile memory
  
  if (!nvsObj.begin("config", false)) {
    #ifdef DEBUG
    Serial.printf("nvsObj object failed to start, looping...\n");
    #endif

    while(1);
  }

  if (nvsObj.isKey("configInit") != 1 || resetNVS == 1) {
    #ifdef DEBUG
    Serial.printf("Config namespace has not be initialized, creating new namespace.\n");
    #endif

    // Load config namespace with parameters
    nvsObj.putBool("timeUpdate", 1);
    nvsObj.putInt("lampBrightVal", 50);
    nvsObj.putInt("utcOffset", 14);
    nvsObj.putInt("alarmHr", 0);
    nvsObj.putInt("alarmMin", 0);

    nvsObj.putBool("configInit", 1);        // Set "already init" status for namespace
  }

  #ifdef DEBUG
  Serial.printf("Config namespace has already been created, obtaining values.\n");
  #endif

  // Obtain values from namespace
  timeUpdate = nvsObj.getBool("timeUpdate");
  lampBrightVal = nvsObj.getInt("lampBrightVal");
  utcOffset = nvsObj.getLong("utcOffset");
  rtcAlarm[0] = nvsObj.getInt("alarmHr");
  rtcAlarm[1] = nvsObj.getInt("alarmMin");

  nvsObj.end();

  #ifdef DEBUG
  Serial.printf("timeUpdate obtained is: %d\n", timeUpdate);
  Serial.printf("lampBrightVal obtained is: %d\n", lampBrightVal);
  Serial.printf("utcOffset obtained is: %d\n", utcOffset);
  Serial.printf("rtcAlarm[0] obtained is: %d\n", rtcAlarm[0]);
  Serial.printf("rtcAlarm[1] obtained is: %d\n", rtcAlarm[1]);
  Serial.printf("alarmSet obtained is: %d\n", alarmSet);
  #endif

  //** FastLED Setup

  // Initialize digit LEDs
  FastLED.addLeds<NEOPIXEL, DIGIPIN0>(digiLEDS[0], NDIGILEDS);
  FastLED.addLeds<NEOPIXEL, DIGIPIN1>(digiLEDS[1], NDIGILEDS);
  FastLED.addLeds<NEOPIXEL, DIGIPIN2>(digiLEDS[2], NDIGILEDS);
  FastLED.addLeds<NEOPIXEL, DIGIPIN3>(digiLEDS[3], NDIGILEDS);

  // Initialize other LEDs
  FastLED.addLeds<NEOPIXEL, MODEPIN>(modeLEDS, NMODELEDS);
  FastLED.addLeds<NEOPIXEL, LAMPPIN>(lampLEDS, NLAMPLEDS);

  // Reset pixel data
  FastLED.clear();
  FastLED.show();

  //** RTC Setup
  if (!RTC.begin()) {
    #ifdef DEBUG
    Serial.printf("RTC object failed to start, looping...\n");
    #endif

    while(1);
  }
  RTC.setHourMode(CLOCK_H24);
  RTC.setEpoch((time_t)timeClient.getEpochTime(), 0);     // Set epoch from NTP using non-unix epoch
  RTC.enableAlarmPin();
  alarmSet = RTC.isAlarm1Enabled();

  #ifdef DEBUG
  Serial.printf("alarmSet obtained is: %d\n", alarmSet);
  Serial.printf("genSetup has finished successfully.\n");
  #endif
}

void wifiNTP() {
  String formatTime;
  char* tkn;
  uint8_t pos = 0;


  #ifdef DEBUG
  Serial.printf("Wifi and NTP needs to be setup.\n");
  Serial.printf("Attempting WIFI connection: connecting to %s\n", ssid);
  #endif

  //** Start WiFi connection
  if (!WiFi.begin(ssid, pswrd)) {
    #ifdef DEBUG
    Serial.printf("WiFi object failed to start, looping...\n");
    #endif

    while(1);
  }

  while (WiFi.status() != WL_CONNECTED) {
    if (millis() - lastBlink > blinkDelay) {
      if (blinkToggle == 0) {
        digiLEDS[3][0].setHSV(0, 0, dispBrightVal);
        blinkToggle = 1;
      } else {
        digiLEDS[3][0].setHSV(0, 0, 0);
        blinkToggle = 0;
      }
      #ifdef DEBUG
      Serial.printf(".");
      #endif

      FastLED.show();
      lastBlink = millis();
    }
  }

  blinkToggle = 1;

  FastLED.clear();
  FastLED.show();

  #ifdef DEBUG
  Serial.printf("\nWifi successfully connected!\n");
  #endif

  //** Start NTP Communication to fetch current time
  timeClient.begin();
  timeClient.setTimeOffset(UTCToSeconds(utcOffsetArray[utcOffset]));     // Set time offset from saved parameters

  #ifdef DEBUG
  Serial.printf("timeClient started!\n");
  Serial.printf("Time offset is: %d:%d\n", utcOffsetArray[utcOffset][0], utcOffsetArray[utcOffset][1]);
  Serial.printf("Time offset in seconds is: %ld\n", UTCToSeconds(utcOffsetArray[utcOffset]));
  Serial.printf("Stopping RTC clock for configuration\n");
  #endif

  if(RTC.isRunning()) {  // Stop clock for configuration 
    RTC.stopClock();
  }

  // Attempt to obtain NTP packet
  while (!timeClient.isTimeSet()) {
    if (timeClient.update() == 0) {
      #ifdef DEBUG
      Serial.printf("NTP update Failed, Trying again.\n");
      #endif
    }
  }

  // Obtain new data from RTC module
  formatTime = timeClient.getFormattedTime();

  #ifdef DEBUG
  Serial.printf("Data received from NTP server: ");
  Serial.println(formatTime);
  #endif

  // Parse string to get hour, minute, and second data

  tkn = strtok(strdup(formatTime.c_str()), ":");

  while (tkn != NULL && !(pos >= 3)) {
    hms[pos] = atoi(tkn);

    #ifdef DEBUG
    Serial.printf("Obtained token #%d: %d\n", pos, hms[pos]);
    #endif

    tkn = strtok(NULL, ":");
    pos++;
  }

  #ifdef DEBUG
  Serial.printf("HMS obtained from parsing function: %d:%d:%d\n", hms[0], hms[1], hms[2]);
  Serial.printf("Setting RTC module with newly obtained time and starting up RTC again.\n");
  #endif 

  RTC.setTime(hms[0], hms[1], hms[2]);
  RTC.startClock();

  // Turn off time and WiFi
  timeClient.end();
  WiFi.disconnect();
  
  #ifdef DEBUG
  Serial.printf("\nWiFi and NTP setup successful.\n\n");
  #endif

}
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

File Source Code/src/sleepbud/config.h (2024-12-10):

/*
    config.h - definitions for GPIO pins and LED array size

    Description: This file holds pin assignments and array size data for easy access.
*/

// LED Pin Defines
#define DIGIPIN0  9
#define DIGIPIN1  10
#define DIGIPIN2  12
#define DIGIPIN3  13

#define MODEPIN   11
#define LAMPPIN   14

// I2C Pins
#define SDAPIN    36
#define SCLPIN    35

// TXS0108E Pins
#define TXSPIN    38

// DS3231SN Pins
#define DSINT     37

// Number of LEDS for LED arrays
#define NDIGILEDS 7
#define NMODELEDS 2
#define NLAMPLEDS 48

// Aux Pins
#define PIRPIN    8
#define BUZZPIN   21

// Button Defines
#define SWITCHBUTTON    7
#define DOWNBUTTON      6
#define UPBUTTON        5
#define MODEBUTTON      4

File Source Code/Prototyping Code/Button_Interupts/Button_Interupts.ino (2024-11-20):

//Ameer Melli 11/14/24
//testing interrupt on pin2, Arduino UNO Rev 3
const byte interruptPin = 21;
volatile bool state = LOW;
int modeCounter = 0; // start at normal mode

void setup() 
{
    pinMode( interruptPin, INPUT_PULLUP );
    Serial.begin(115200);
    Serial.flush();
    Serial.println("Started");
    pinMode( interruptPin, INPUT_PULLUP );
    attachInterrupt(digitalPinToInterrupt(interruptPin), ISR_button_pressed, FALLING);
}

void loop() 
{
    if (state)//if an interrup has occured
    {
        Serial.print("Leaving Mode "); Serial.println(modeCounter);
        modeCounter = modeCounter + 1;
        Serial.print("Interrupt at time "); Serial.println(millis());
        delay(1000);//simulate task executing
        if (digitalRead(interruptPin))//if button is released let ISR set flag.
        {
            attachInterrupt(digitalPinToInterrupt(interruptPin), ISR_button_pressed, FALLING );
            state = false;//reset interrupt flag
        }
            
    }
}


void ISR_button_pressed(void) 
{
    if (!state)//set flag to low if flag is true
    {
        state = true;//set flag
        //Serial.print("Activated "); Serial.println(modeCounter); //cant add in interupts
        detachInterrupt( digitalPinToInterrupt(interruptPin) );
        
    }//if
}

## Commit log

2024-10-24 Work Log Update
    - Create LED Display Testbench
2024-10-24 Initialize KiCad
    Couple Schematics In to Test
2024-10-24 New SleepBud Folder Directory
    sup
    [SleepBud.kicad_pcb, SleepBud.kicad_sch]
2024-10-26 Version 10/25
    Added connections
    [SleepBud.kicad_sch]
2024-10-26 new version with updated stuff
    [SleepBud.kicad_sch]
2024-11-02 SleepBud Schematic 11/1/2024
    [SleepBud.kicad_sch]
2024-11-02 Test code for passive buzzer
    This generates 90+ dB for the buzzer with delays and changing tones. There is also code for an active buzzer if we like that better.
    [ECE411_PassiveBuzzerTest.ino]
2024-11-06 Create Test Program for LEDs
    - Created test program for lighting up LEDs
    - Created wrapper function to display number based on preset array
2024-11-06 Version 1.1
    [SleepBud.kicad_sch]
2024-11-06 Finished Wiring Schematic
    Wiring is finished, however there are 10 errors left that need to be checked/ fixed
    [SleepBud.kicad_sch]
2024-11-06 MultiLED Array Support
    - Can now interface with multiple instances of LED arrays with single function
    - Can set color of a set of arrays
    - Digit arrays are handled based on input number
2024-11-06 Added Footprints to most things
    [SleepBud.kicad_pcb, SleepBud.kicad_sch]
2024-11-07 Initial Program Setup
    - Transferred pre-processor directives, objects, and variables from test programs to main
    - Created config.h to hold pin assignments and LED array lengths
2024-11-07 Finish Most Footprint, Started Layout
    [SleepBud.kicad_pcb, SleepBud.kicad_sch]
2024-11-07 Moving PIR
    Moving PIR to correct folder.
    [PIR_ECE411.ino]
2024-11-08 Moving Buzzer Folder
    This moves the buzzer code to the correct folder
    [ECE411_PassiveBuzzerTest.ino]
2024-11-08 Revert "Moving Buzzer Folder"
    This reverts commit 946b4f6aadbfe2fb92f8ac278ed7cf92d526357d.
    [ECE411_PassiveBuzzerTest.ino]
2024-11-08 Buzzer Folder without DS
    This moves the buzzer into the correct folder.
    [ECE411_PassiveBuzzerTest.ino]
2024-11-08 For Switch (needs to cut)
    This is just a starting box for how the kill switch can be held.
    [Kill_Switch_box_ECE411.stl]
2024-11-08 Switched some footprints and schematics
    [SleepBud.kicad_pcb, SleepBud.kicad_sch]
2024-11-08 Updated Footprints
    Footprint for WB2812B LED was personalized
    [SleepBud.kicad_pcb, SleepBud.kicad_sch]
2024-11-09 Create Setup Functions
    - Created genSetup to setup all objects needed for clock
    - Created wifiNTP to connect to WIfI to update time
    - Created rtcSet to set current time on RTC module
    - Added LED functions from LEDTest program
2024-11-09 Bug FIxes
    - Added WiFi cred variables that were forgotten
    - Added valid checks for begin functions
    - Added configInit key to Preferences to check if namespace has been allocated
    [sleepbud.ino]
2024-11-09 Adding Clock Digits (unsized)
    This was based on a reference found online and needs to be sized down for our needs (optional needs diffuser white prints to cover each digit side)
    [ClockDigits_V1_ECE411.stl]
2024-11-10 just moved some stuff around and changed some texts
    [SleepBud.kicad_sch]
2024-11-11 Placed Parts to Potential area on Layout
    [SleepBud.kicad_pcb, SleepBud.kicad_sch]
2024-11-12 Back of PCB Almost Done, Started on Front
    [SleepBud.kicad_pcb, SleepBud.kicad_sch]
2024-11-14 PCB Work on V1.1
    [SleepBud.kicad_pcb]
2024-11-14 Pads
    Pads for 12V-5V chip
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2024-11-14 PCB Layout Routing Rough Draft Finished
    [SleepBud.kicad_pcb, SleepBud.kicad_sch]
2024-11-14 change title for layput
    [SleepBud.kicad_pcb]
2024-11-15 Fixed all violations on PCB
    Just need to work on grounding parts, and switching mosfets, adding connections
    [SleepBud.kicad_pcb, SleepBud.kicad_sch]
2024-11-16 PCB Done Needs Checking Over
    All NECESSARY warnings/errors are resolved just need checking with entire team/design review by others
    [SleepBud.kicad_pcb, SleepBud.kicad_sch]
2024-11-16 Added LED Set Helper Functions
    - Added setDigitLED function to set HSV per digit on display
    - Added timeDisplay as wrapper for setDigitLED
    - Created setAuxLED as helper for setting up aux LEDs (mode LEDs, lamp LEDs
2024-11-16 Bug Fixes
    - Fixed narrowing warning due to incorrect casting to uint8_t
    - Added disconnect code for WiFi
    [sleepbud.ino]
2024-11-18 Changed PMosfet
    Change the Mosfet can be seen on schematic and PCB layout
    [SleepBud.kicad_pcb, SleepBud.kicad_sch]
2024-11-18 Added Some Ground Vias to each Corner of the Board
    Still missing the ground stitching for some components, will work on it it later
    [SleepBud.kicad_pcb, SleepBud.kicad_sch]
2024-11-19 Added Some More Ground Vias
    I think I did the ground stitching correctly, need team to check if its correct.
    [SleepBud.kicad_pcb]
2024-11-19 Bug Fixes
    - Added debug code to check for successful NTP packet fetch
    [sleepbud.ino]
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2024-11-20 Kill switch V2
    This is just the sized version for the kill switch to slide into.
    [KillSwitch_V2_ECE411.stl]
2024-11-20 Finished PCB V1.5
    Added LEDs to see if PCB is getting power
    Changed TestPoint sizes
    Added more grounds to even out board
    [SleepBud-B_Cu.gbr, SleepBud-B_Mask.gbr, SleepBud-B_Paste.gbr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]
2024-11-20 Added more grounds vias based off video
    also created new gerber files
    [SleepBud-B_Cu.gbr, SleepBud-B_Mask.gbr, SleepBud-B_Paste.gbr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]
2024-11-24 Final PCB
    [SleepBud-B_Cu.gbr, SleepBud-B_Mask.gbr, SleepBud-B_Paste.gbr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]
2024-12-01 Minor Fixes
    - S3 required I2C pins be declared
    - OE for logic shifter now has a pin t control data out to LEDs
    [config.h, sleepbud.ino]
2024-12-01 PIR Control
    - Added PIR Enable/Disable LED code
    - Can use PIR to turn on/off LEDs using interrupt
2024-12-03 Mode Test created
    This tests the logic of the interrupts for the mode and the buttons.
2024-12-04 This is untested Mode interrupts integration
    This still needs mode 4 to be added. Also is untested
2024-12-05 changed schematic from 12v/3a to 7v 3a
    [SleepBud.kicad_sch]
2024-12-05 wrote 7v instead of 9v on schematic
    [SleepBud.kicad_sch]
2024-12-05 Updated for case 4 set time manually
    This is the updated test case
2024-12-05 chnaged power supply once more
    [SleepBud.kicad_sch]
2024-12-05 Updated sleepbud for modes (untested)
    This adds case 4 to the sleep bud main
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2024-12-05 Moved some stuff around to make it look pretty
    [SleepBud.kicad_sch]
2024-12-05 Add buttons to config and remove from main
2024-12-07 Reconfigured LED and Buzzer Setup
    - Fixed RTC call (update changed function)
    - Added Buzzer Pin config
    - Add Reversed LED array matrix data for flipped display
    [config.h, sleepbud.ino]
2024-12-10 1.6 Final version of both schematic and pcb
    This is the final version. Includes the change from 12V to 5V power supply, resistor values changed to the audio module and esthetical changes to the schematic including resizing of page and rewiring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
    [SleepBud.kicad_pcb, SleepBud.kicad_sch]
2024-12-10 Implemented Polling Functions for Buttons
    - Changed interrupts to polling for user UI
    - Reorganized variables from prior merges
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2024-12-12 Bug Fix for Test Function
    [sleepbud.ino]
2024-12-12 Fixing color table stuff
    [sleepbud.ino]
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2024-12-13 Added STL files for Case
    [ClockDigits_V1_ECE411.stl, KillSwitch_V2_ECE411.stl, Kill_Switch_box_ECE411.stl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]
2024-12-13 Added Blinking to Wifi Fetch and Fixed Colors
    [sleepbud.ino]
2024-12-14 Fixed Time Keeping Bug
    [sleepbud.ino]
